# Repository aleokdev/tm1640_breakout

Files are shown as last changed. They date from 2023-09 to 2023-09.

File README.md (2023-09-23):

# TM1640 Breakout Board
A breakout board made for the chinese Titan Micro Electronics TM1640 chip, commonly used in cheap 7-segment displays.

The board has been designed mostly with size in mind to be able to plug it into a breadboard. It is 14x8 breadboard pins long (1.4x0.8in, or around 35.56x20.32mm). It follows the datasheet design (Using both a 10k pullup resistor and 100p capacitor for both data lines, and a 100nF as well as a 100uF capacitor for the VCC pin).

Contributions as well as criticism and suggestions are more than welcome.

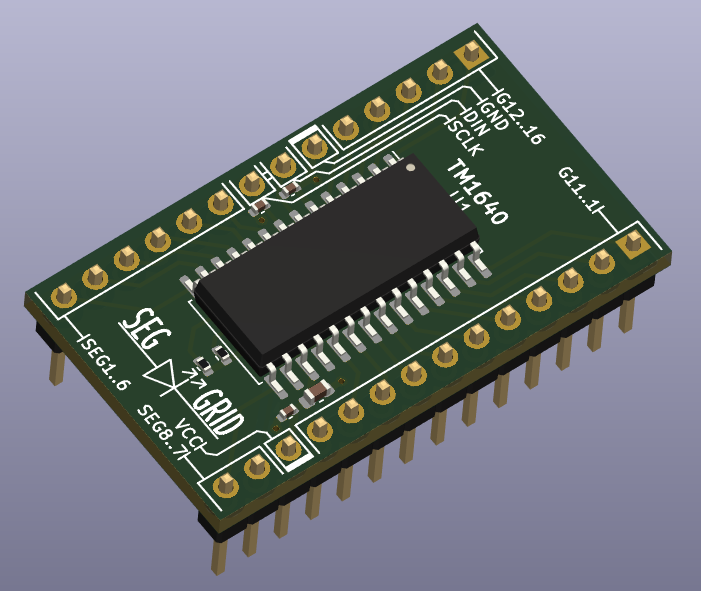
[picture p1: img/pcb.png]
PCB preview


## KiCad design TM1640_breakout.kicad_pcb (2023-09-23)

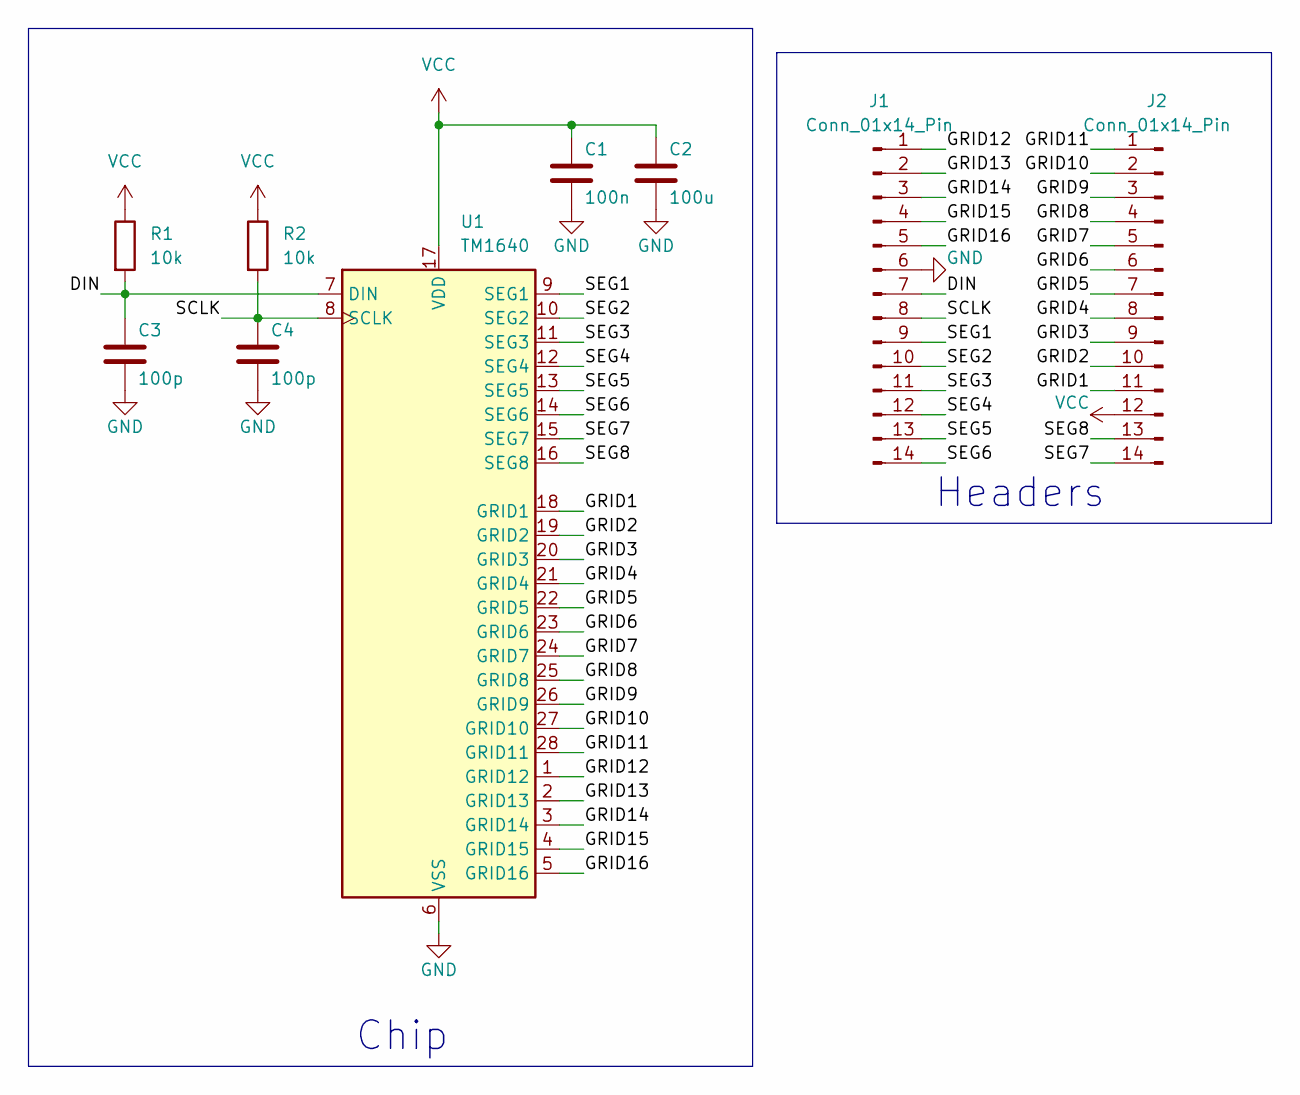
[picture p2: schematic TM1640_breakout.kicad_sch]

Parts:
C1: 100n; C_0402_1005Metric
C2: 100u; C_0603_1608Metric
C3, C4: 100p; C_0402_1005Metric
J1, J2: Conn_01x14_Pin; PinHeader_1x14_P2.54mm_Vertical
R1, R2: 10k; R_0402_1005Metric
U1: TM1640; SOIC-28W_7.5x17.9mm_P1.27mm

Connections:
/DIN: C3.1, J1.7, R1.2, U1.7 (DIN)
/GRID1: J2.11, U1.18 (GRID1)
/GRID2: J2.10, U1.19 (GRID2)
/GRID3: J2.9, U1.20 (GRID3)
/GRID4: J2.8, U1.21 (GRID4)
/GRID5: J2.7, U1.22 (GRID5)
/GRID6: J2.6, U1.23 (GRID6)
/GRID7: J2.5, U1.24 (GRID7)
/GRID8: J2.4, U1.25 (GRID8)
/GRID9: J2.3, U1.26 (GRID9)
/GRID10: J2.2, U1.27 (GRID10)
/GRID11: J2.1, U1.28 (GRID11)
/GRID12: J1.1, U1.1 (GRID12)
/GRID13: J1.2, U1.2 (GRID13)
/GRID14: J1.3, U1.3 (GRID14)
/GRID15: J1.4, U1.4 (GRID15)
/GRID16: J1.5, U1.5 (GRID16)
/SCLK: C4.1, J1.8, R2.2, U1.8 (SCLK)
/SEG1: J1.9, U1.9 (SEG1)
/SEG2: J1.10, U1.10 (SEG2)
/SEG3: J1.11, U1.11 (SEG3)
/SEG4: J1.12, U1.12 (SEG4)
/SEG5: J1.13, U1.13 (SEG5)
/SEG6: J1.14, U1.14 (SEG6)
/SEG7: J2.14, U1.15 (SEG7)
/SEG8: J2.13, U1.16 (SEG8)
GND: C1.2, C2.2, C3.2, C4.2, J1.6, U1.6 (VSS)
VCC: C1.1, C2.1, J2.12, R1.1, R2.1, U1.17 (VDD)

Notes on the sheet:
Chip
Headers

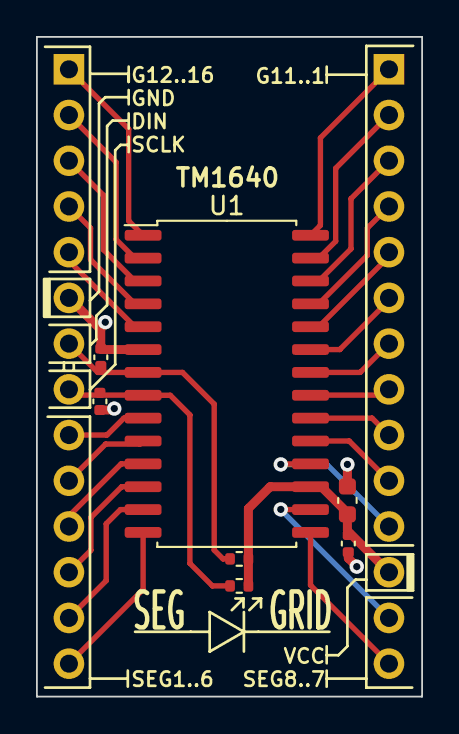
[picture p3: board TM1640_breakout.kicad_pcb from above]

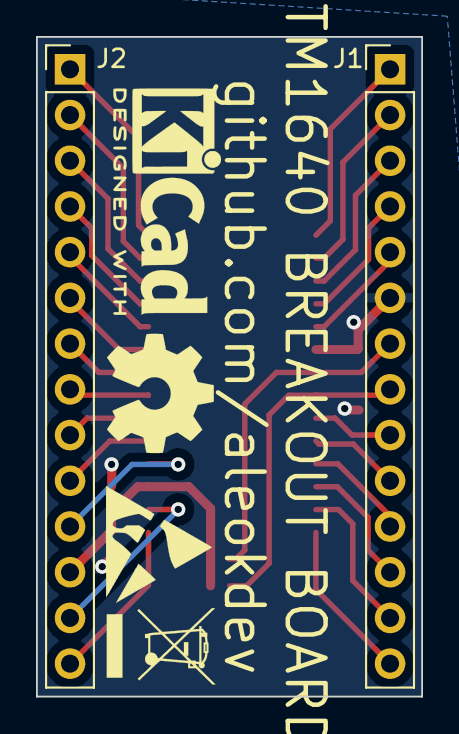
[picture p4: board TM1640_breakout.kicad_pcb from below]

Board: 2 copper layers, 21.4 x 36.6 mm, 9 parts (2 on the bottom side), 28 nets.
